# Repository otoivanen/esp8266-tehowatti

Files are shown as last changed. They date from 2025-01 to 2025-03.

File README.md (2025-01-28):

# Introduction
This project aims to create a custom device with esp8266 based microcontroller to track floor heating system's inlet- and outlet temperatures and allow to control the heating system's temperature dropping functionality.
The device can be integrated to any homeautomation system with MQTT capabilities.

- Reads two DS18B20 sensors
- Reports sensor values to selected MQTT topics
- Controls external components via relay, controllable with MQTT
- Display to show errors and status values
- LED to indicate statuses with guick glance
- Web UI for configuring the device, WiFi AP / WLAN
- Intended to integrate into Home Assistant

# Project structure
Project is a normal Arduino/ESP8266 created in VSCode PlatformIO extension - so the project structure differs a bit from traditional program created with Arduino IDE.

1) Install VSCode
2) Install PlatformIO extension
3) Clone the repository
4) Access the project through PlatformIO extension
5) Upload the program to device with PlatformIO
6) Upload the static files in Data directory to device SPIFFS with PlatformIO

The Data -directory contains all static files to be saved in the SPIFFS.

# Hardware
This is just an example of the bill of materials for the project. With small changes you can adapt your own hardware. List of hardware used in this project:
- Wemos D1 Mini
- 0.96" OLED I2C generic display
- 2x DS18B20 temperature sensors
- Relay board with 3.3V coil voltage
- WS1812B LED
- 3D printed case
- Cable glands
- Dupont wires
- Preferably Home Assistant or similar homeautomation system

## Case
The case has been designed with SolidWorks and needed STL & 3MF files are published in MakerWorld community
[Wemos D1 Mini project enclosure](https://makerworld.com/en/models/946838#profileId-913814)

# TO-DO
- Controllability
    - Implement relay class
    - Implement relay control through mqtt
    - Implement relay control through web ui
- Status indication
    - Implement sensor values & WiFi status to OLED display
    - Implement logics for status LED controlling
- Configuration
    - Implement assigning scanned sensor adresses into inlet/outlet temps via web UI
- Documentation
    - Draw wiring schema for device & boiler

# Images
##
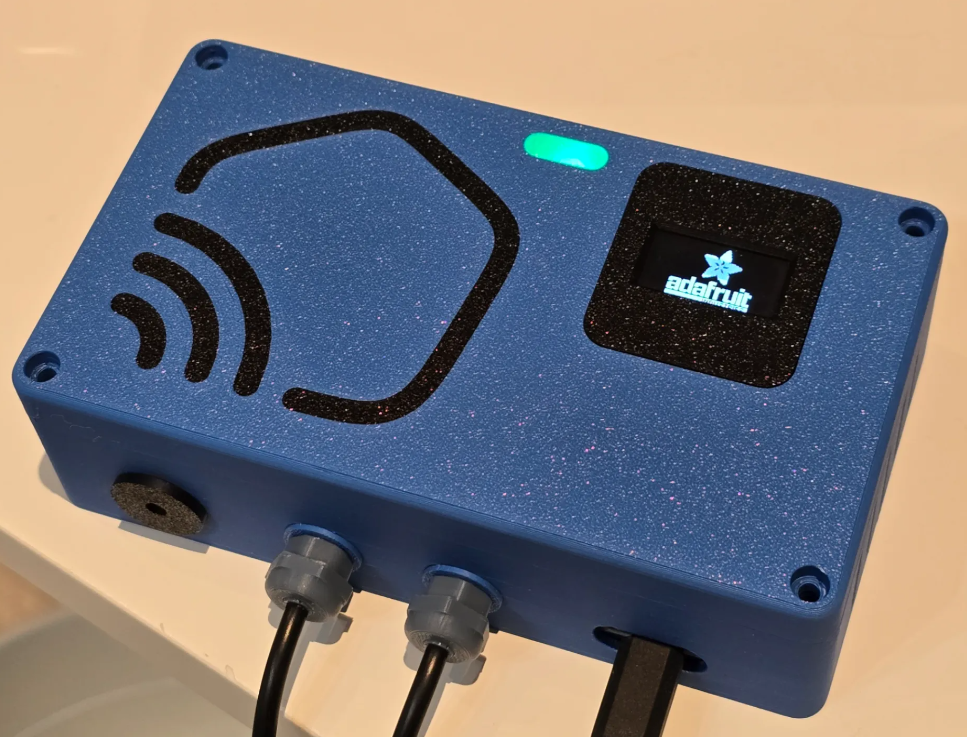
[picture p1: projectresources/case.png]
case


## Configuration UI runnin on AP or WLAN to store settings
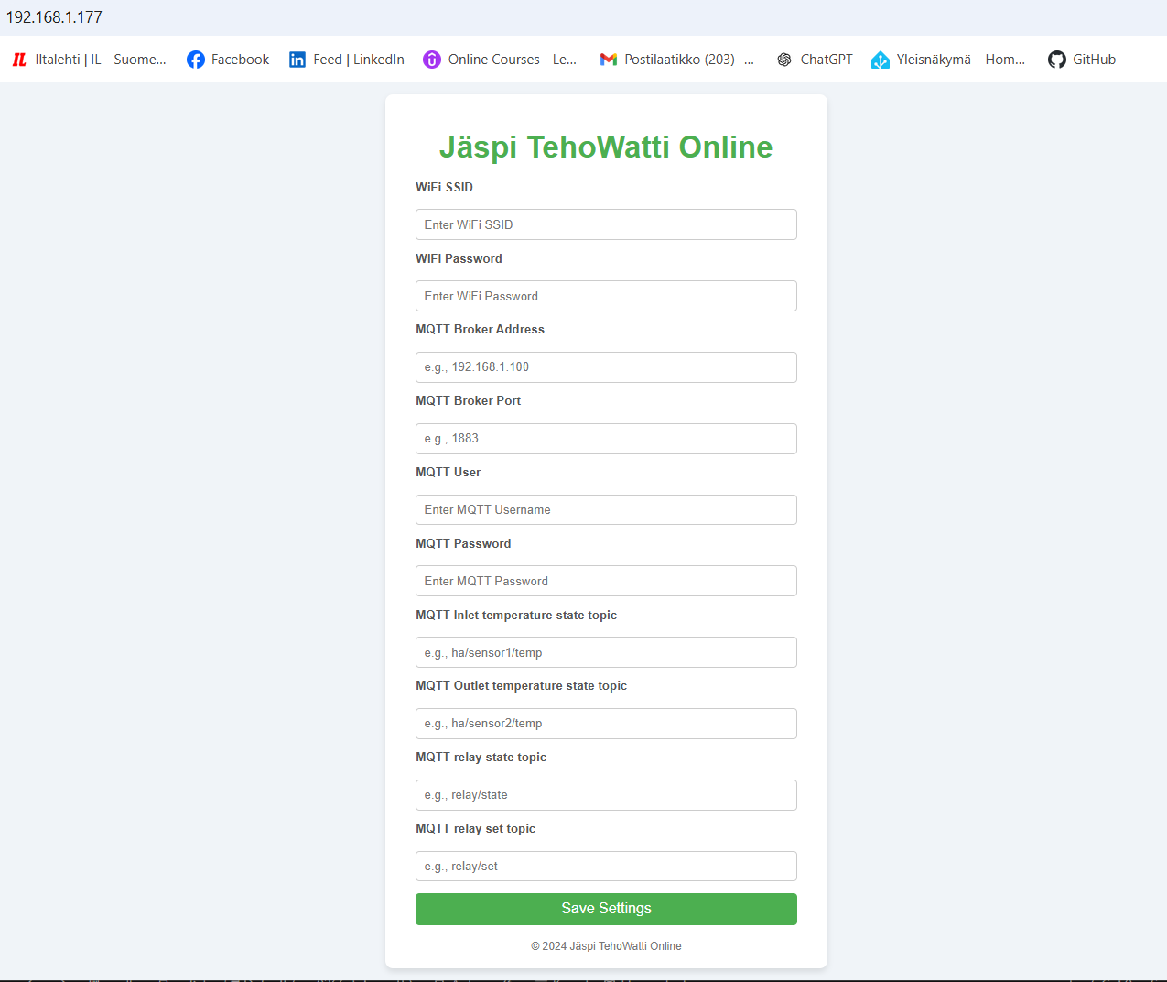
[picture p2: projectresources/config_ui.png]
configurationui


## Home assistant integration
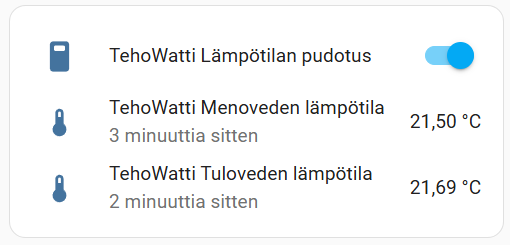
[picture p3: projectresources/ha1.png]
ha1

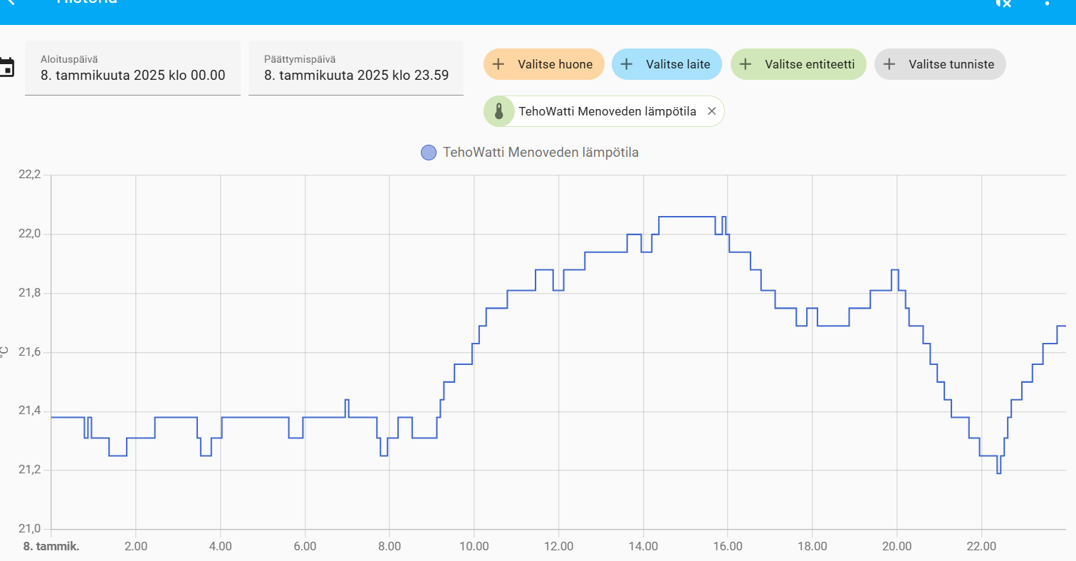
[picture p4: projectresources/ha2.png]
ha2


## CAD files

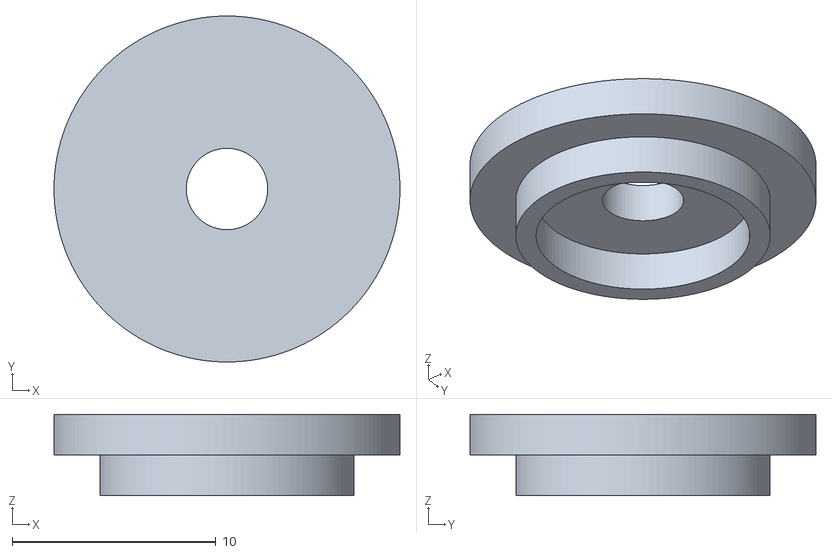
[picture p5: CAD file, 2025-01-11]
case/STL/CableGland1^case_assembly.STL
17.0 x 17.0 x 4.00

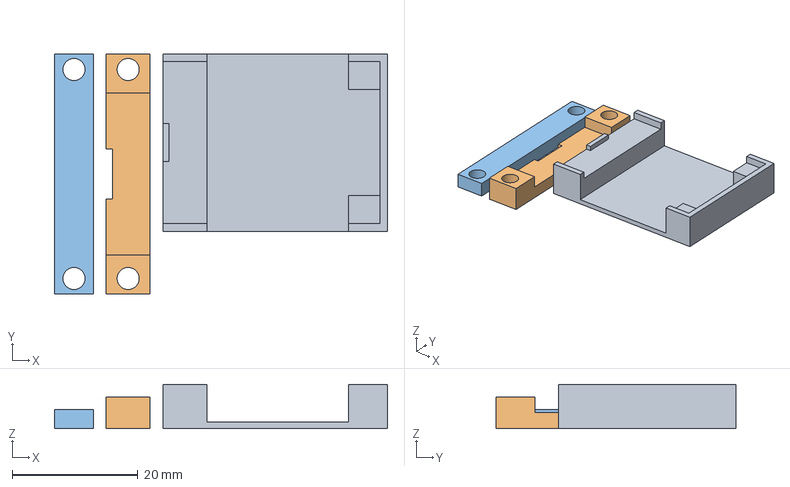
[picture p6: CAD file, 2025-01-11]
case/CradleAssembly.3mf
52.9 x 38.2 x 7.00 mm
CradleAssembly
CradleAssembly_3
CradleAssembly_2

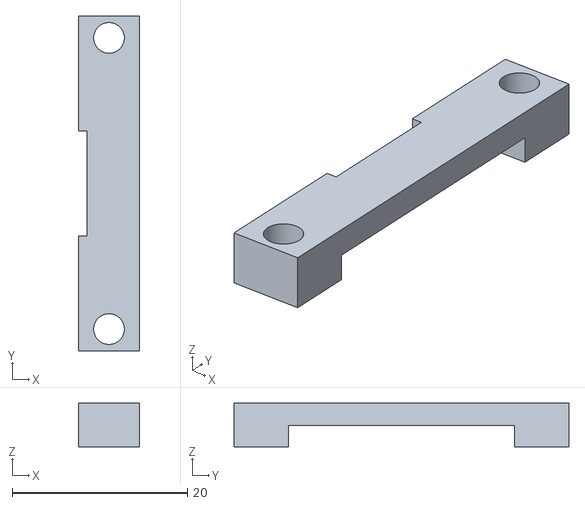
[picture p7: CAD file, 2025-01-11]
case/STL/Wemos_cradlelock_2^CradleAssembly.STL
7.00 x 38.2 x 5.00

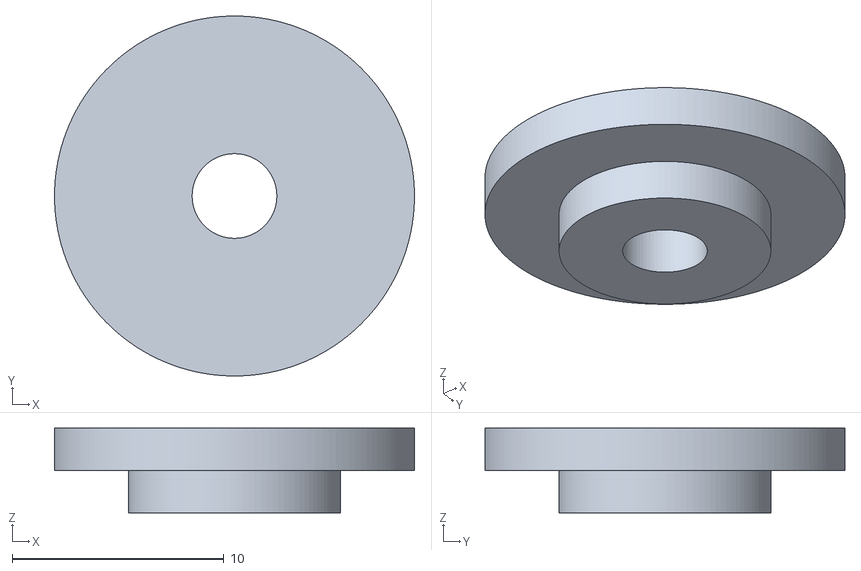
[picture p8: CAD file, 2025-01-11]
case/STL/CableGland2^case_assembly.STL
17.0 x 17.0 x 4.00

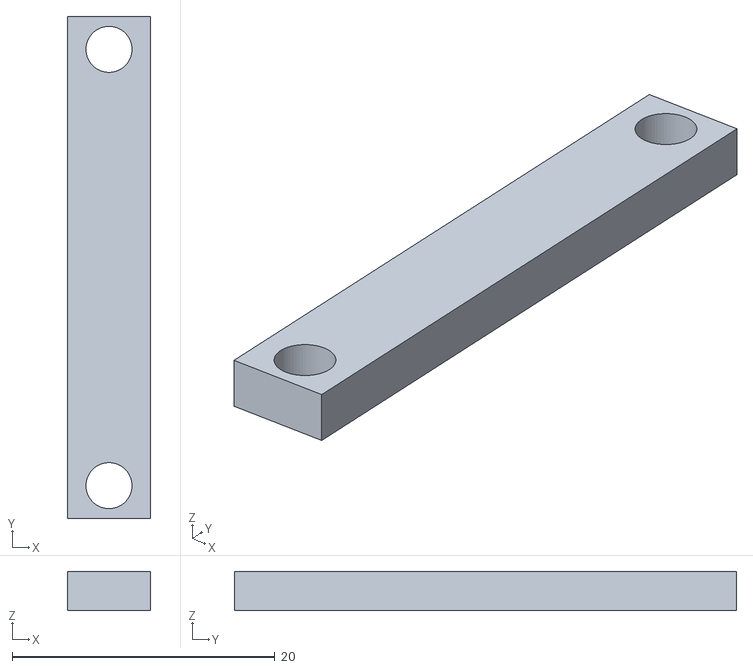
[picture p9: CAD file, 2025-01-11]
case/STL/Wemos_cradlelock_1^CradleAssembly.STL
6.30 x 38.2 x 3.00

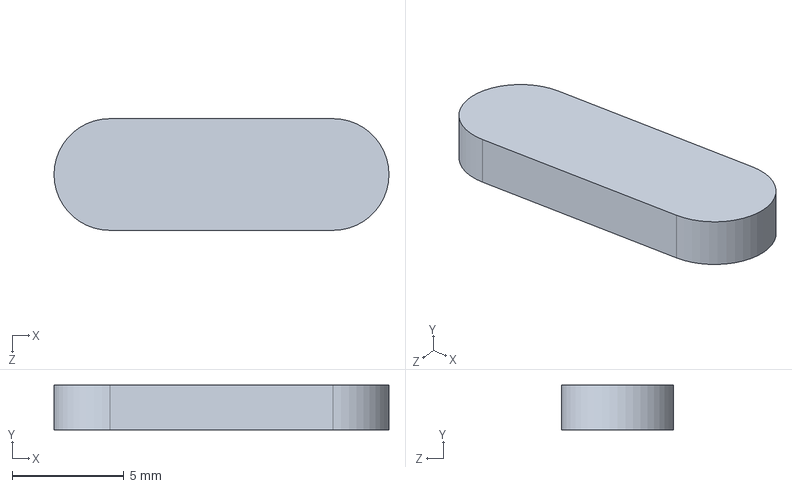
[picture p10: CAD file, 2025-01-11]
case/Body2.SLDPRT
15.0 x 2.00 x 5.00 mm

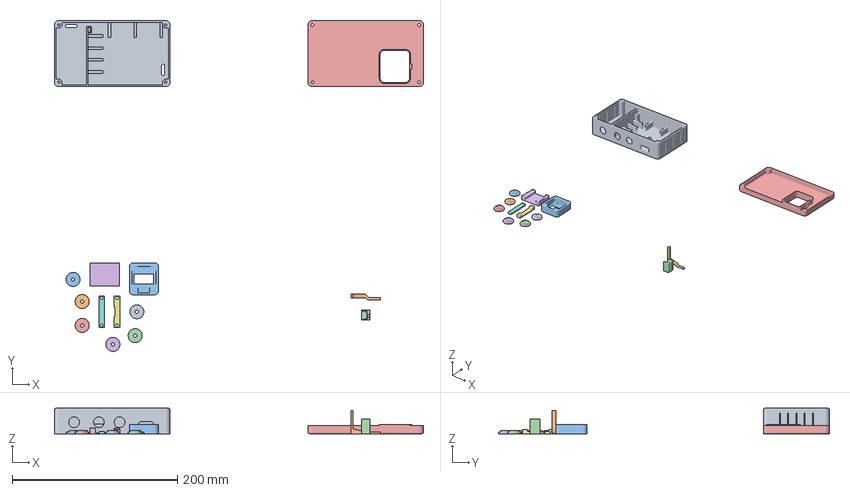
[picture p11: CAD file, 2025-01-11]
case/STL/case_project.3mf
447.2 x 400.9 x 31.0 mm
case_body.STL
Ledbase.STL
bezel.STL
LedCradle.STL
Assembly
Wemos_cradle.STL
Wemos_cradlelock_2^CradleAssembly.STL
Wemos_cradlelock_1^CradleAssembly.STL
CableGland2^case_assembly.STL x 3
CableGland1^case_assembly.STL x 3

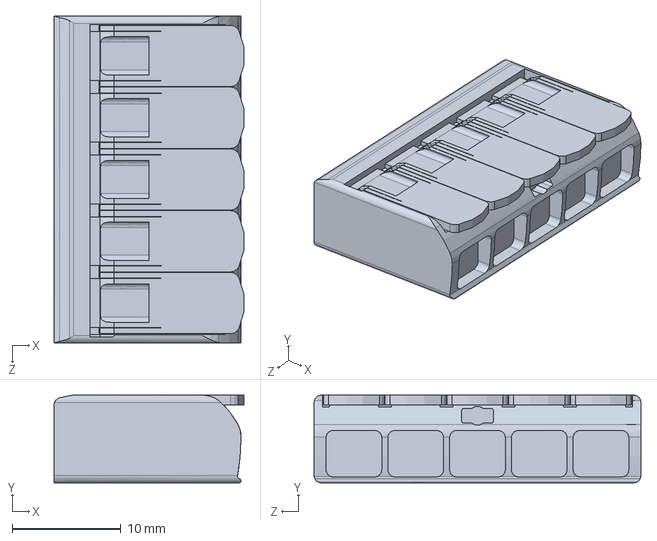
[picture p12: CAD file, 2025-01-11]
case/WAGO 221-615.SLDPRT
17.5 x 8.08 x 30.1 mm

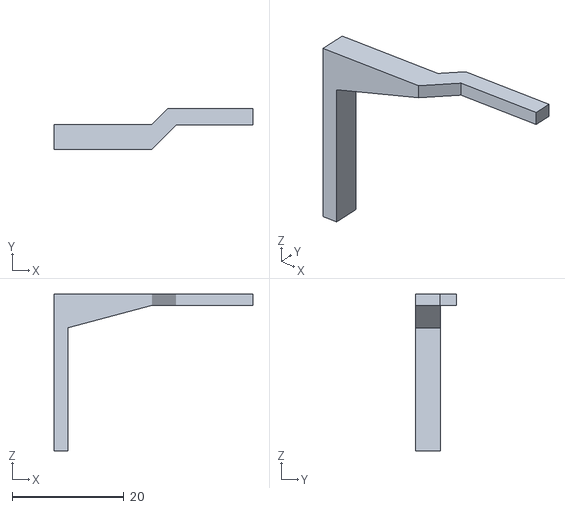
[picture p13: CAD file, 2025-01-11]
case/STL/Ledbase.STL
35.6 x 7.35 x 28.0

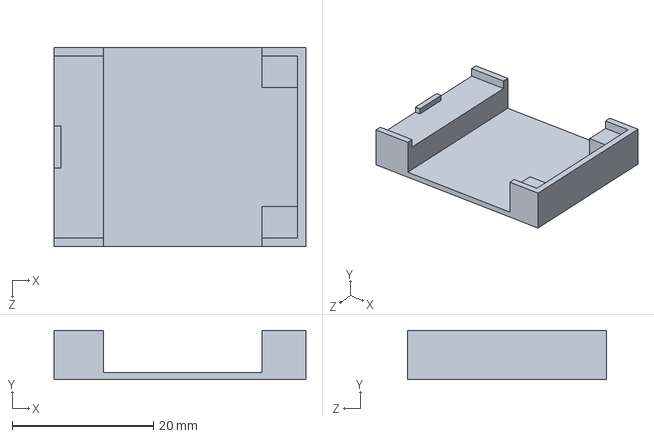
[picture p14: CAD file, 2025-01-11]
case/Wemos_cradle.SLDPRT
35.7 x 7.00 x 28.2 mm

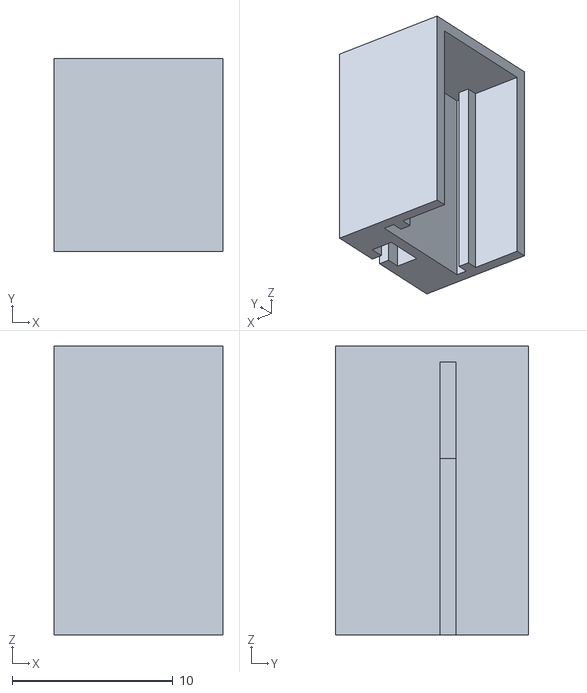
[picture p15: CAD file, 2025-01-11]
case/STL/LedCradle.STL
10.5 x 12.0 x 18.0

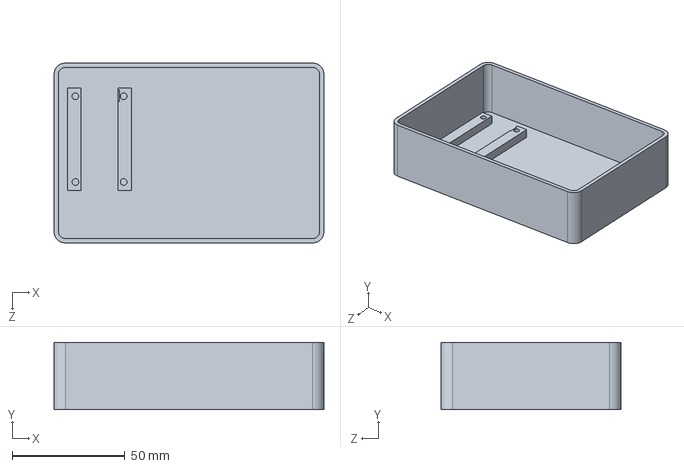
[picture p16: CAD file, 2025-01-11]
case/case_body.SLDPRT
120.0 x 30.0 x 80.0 mm

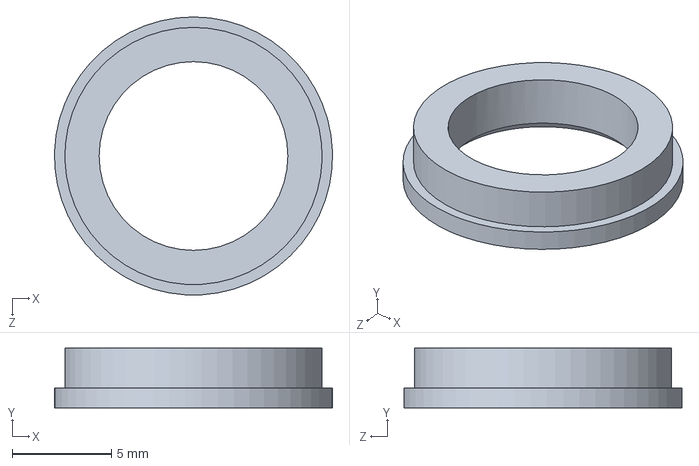
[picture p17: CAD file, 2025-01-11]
case/STL/cableGland_flange.SLDPRT
14.0 x 3.00 x 14.0 mm

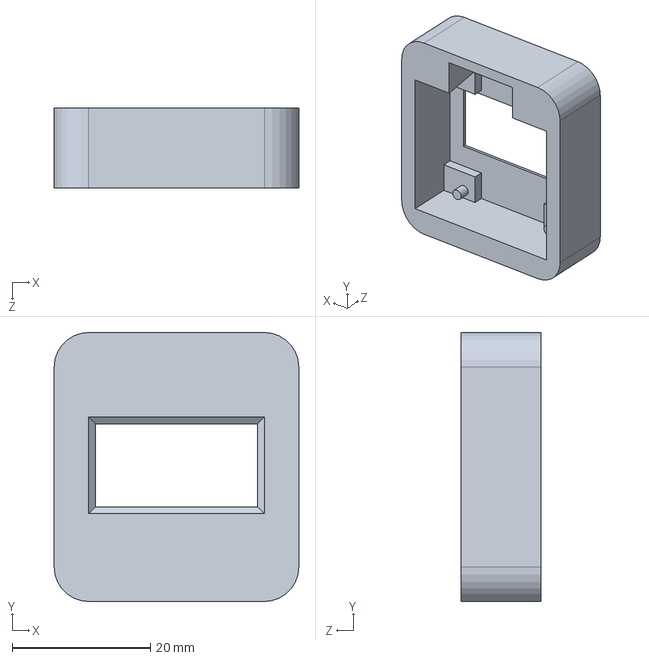
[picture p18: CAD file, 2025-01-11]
case/bezel.SLDPRT
35.4 x 38.9 x 11.5 mm

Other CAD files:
case/Relay.SLDPRT
case/STL/Lid.STL
case/Body4.SLDPRT
case/Body1.SLDPRT
case/Body3.SLDPRT
case/Cable gland.SLDPRT
case/M12 Thin hex nut.SLDPRT
case/STL/Wemos_cradle.STL
case/STL/bezel.STL
case/STL/cableGland_flange.STL
case/STL/case_body.STL
case/Wago serie 221.SLDPRT

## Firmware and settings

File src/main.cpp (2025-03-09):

/*
ESP8266-Tehowatti program controls a device that reads two DS18B20 temperature sensors, and reports the values through MQTT
to configurable topics. The program also controls a relay based on MQTT messages and/or HTTP-requests. The device can be configured and
status checked through WebUI served from the device's webserver.

Main program initializes the needed objects and performs the main loop of checking connections and connecting as needed, switching between STA/AP-modes,
handling MQTT-communication and HTTP-requests. The detailed logics of each functionality is encapsulated inside the corresponding class. Main events
of the main in addition to status checks and calling functions from other classes is to handle the MQTT-messaging. It includes also few global functions
to allow global messaging between multiple classes.

Author: Oskari Toivanen
Date: 2025-03-09
*/

#include <Arduino.h>
#include <WiFiManager.h>
#include <WebServerManager.h>
#include <secrets.h>
#include <FileManager.h>
#include <ArduinoJson.h>
#include <PubSubClient.h>
#include <SensorManager.h>
#include <ConfigManager.h>
#include <Wire.h>
#include <Adafruit_NeoPixel.h>
#include <Relay.h>
#include <Global_functions.h>
#include <OLEDManager.h>
#include <LEDManager.h>

const int ONE_WIRE_PIN = 16; // Pin where onewire sensors are connected
const char* DEVICE_NAME = "TehoWatti";
unsigned long MQTT_RECONNECT_INTERVAL = 10000;
unsigned long SENSOR_VALUE_MIN_PUBLISH_INTERVAL = 5000;
unsigned long SENSOR_VALUE_MAX_PUBLISH_INTERVAL = 300000; // Publish sensor values every 5 mins minimum
unsigned long RELAY_STATE_PUBLISH_INTERVAL = 300000; // Publish relay state by force every 5 mins

FileManager fm; // Filemanager object for reading & writing to files
WiFiManager wm; // WiFiManager object to control WiFi connectivity
WiFiClient wiFiClient; // Initialize separate WiFi Client to interact with mqtt server on different port
PubSubClient mqttClient(wiFiClient); // Mqtt client for mqtt messaging
SensorManager sensors(ONE_WIRE_PIN); // Initialize the sensor manager
ConfigManager config(fm);
Relay relay(14); // Initialize relay in output pin 14
WebServerManager server(80, config, sensors, relay); // Webserver to run on port 80 for http connections
OLEDManager oled; // Init display object
LEDManager led; // Init the led control


// Declare function prototypes here to place them below loop () for better readability
void connectMqtt();
bool isPublishAllowed();
void publishSensorValues();
void callback(char* topic, byte* payload, unsigned int length);
void publishRelayState();

void setup() {
  // Initialize and start the display
  oled.begin(SSD1306_SWITCHCAPVCC, 0x3C);
  oled.showBootMsg("Booting..");

  // Initialize and start the led operation, show alert color until fully booted
  led.enable();
  led.alert();

  Serial.begin(9600); // Open the serial port
  fm.begin(); // Initialize the FS
  config.loadConfig(); // Load all configs from file

  // Set the sensor addresses from config
  sensors.setInletSensorAddress(config.getInletSensorAddress());
  sensors.setOutletSensorAddress(config.getOutletSensorAddress());

  wm.setCredentials(config.getSSID(), config.getWiFiPassword(), DEVICE_NAME);
  
  oled.showBootMsg("Trying to establish WiFi Connection");
  if(!wm.connect()) {
    oled.showBootMsg("WiFi failed, starting AP");
    wm.startSoftAP();
  }

  server.begin(); // Start the web server
  mqttClient.setServer(config.getMqttServer(), config.getMqttPort());
  mqttClient.setKeepAlive(15);
  mqttClient.setCallback(callback); // Assign callback function to execute when MQTT-msg is received
  connectMqtt();
  
  oled.clearDisplay();
  oled.display();
}

void loop() {
  // Update the status led state on every cycle
  led.setStatus(wm.isAPOn(), mqttClient.connected(), relay.getState());

  // Ensure wifi is connected, if not start softAP for a period of time before reconnecting
  wm.checkWiFiStatus(); 

  // Ensure mqtt broker is connected and attempt reconnect if not
  if (!mqttClient.connected() && !wm.isAPOn()) {
    connectMqtt();
  }

  server.handleClient();    // Handle the webserver client requests
  wm.checkAPClientCount();  // Check nbr of softap clients if established. Non-blocking function.
  sensors.readSensors();    // Read the sensor values on interval specified in the sensor class
  mqttClient.loop();        // Handle MQTT-messages
  publishSensorValues();    // Publish sensor values
  publishRelayState();      // Force publish relay state in case of unknown state

  // Update the OLED -display rows if states have changed
  oled.updateDisplay(sensors.getInletTemp(), sensors.getOutletTemp(), relay.getState(), wm.getIP(), wm.getMode(), mqttClient.connected());
}

/**
 * @brief Checks MQTT-connection status and reconnects on preset interval if needed
 * 
 * If WiFi-connection is established, and time defined in MQTT_RECONNECT_INTERVAL constant
 * has passed, device retries the connection to MQTT-broker. After succesful connection the needed
 * topics are being subscribed.
 */
void connectMqtt() {
  static unsigned long lastConnectionAttempt = 0;

  if(wm.status() == WL_CONNECTED && millis() - lastConnectionAttempt > MQTT_RECONNECT_INTERVAL) {

    Serial.println("Trying to establish mqtt broker connection");

    if(mqttClient.connect(DEVICE_NAME, config.getMqttUser(), config.getMqttPassword())) {
      Serial.println("Connected to mqtt broker succesfully");
      mqttClient.subscribe(config.getRelaySetTopic()); // Subscribe to relay set topic for receiving control msg
    } else {
      Serial.print("Failed to connect mqtt broker with errorcode: ");
      Serial.println(mqttClient.state());
    }

    lastConnectionAttempt = millis();
  }
}

/**
 * @brief Determines if a sensor value is allowed to be published over MQTT
 * 
 * The function checks two conditions to allow publishing:
 * 1. If the elapsed time since last publish exceeds the minimum interval and
 * the temperature change exceeds a defined treshold (0.1c)
 * 2. If the maximum allowed publish interval has been exceeded, regardless of temperature change
 * 
 * Additionally, publishing is allowed only if the MQTT client is currently connected.A0
 * 
 * @param lastPublish the timestamp (in milliseconds) of the last succesful publish
 * @param lastTemp the last published temperature value
 * @param currentTemp the current temperature reading
 * @return true if publishing is allowed based on the condition, false otherwise
 */
bool isPublishAllowed(unsigned long &lastPublish, float &lastTemp, float &currentTemp) {
  unsigned long fromLastPublish = millis() - lastPublish;

  if (!mqttClient.connected()) { return false; }

  if((fromLastPublish > SENSOR_VALUE_MIN_PUBLISH_INTERVAL && abs(lastTemp - currentTemp) > 0.1) || fromLastPublish > SENSOR_VALUE_MAX_PUBLISH_INTERVAL) {
    return true;
  }
  
  return false;
}

/**
 * @brief Handles the publishing of the sensor values to MQTT broker.
 * 
 * The function maintains the previous temperature- and publishtime values for determining if publishing is allowed.
 * Function fetches latest readings for both sensors and publishes the values into MQTT topics defined in configs if allowed.
 */
void publishSensorValues() {
  static unsigned long lastInletTempPublish = 0; // static will retain the value from last execution
  static unsigned long lastOutletTempPublish = 0;

  char buffer[16]; // Shared buffer for publishing

  float inletTemp = sensors.getInletTemp();
  static float lastInletTemp = 0;
  float outletTemp = sensors.getOutletTemp();
  static float lastOutletTemp = 0;

  // Publish inletTemp
  if(isPublishAllowed(lastInletTempPublish, lastInletTemp, inletTemp)) {
    dtostrf(inletTemp, 6, 2, buffer); // Convert float to string
    mqttClient.publish(config.getInletTempStateTopic(), buffer);
    Serial.print("Inlet temperature published: ");
    Serial.println(inletTemp);
    lastInletTempPublish = millis();
    lastInletTemp = inletTemp;
  }

  // Publish outletTemp
  if(isPublishAllowed(lastOutletTempPublish, lastOutletTemp, outletTemp)) {
    dtostrf(outletTemp, 6, 2, buffer); // Convert float to string
    mqttClient.publish(config.getOutletTempStateTopic(), buffer);
    Serial.print("Outlet temperature published: ");
    Serial.println(outletTemp);
    lastOutletTempPublish = millis();
    lastOutletTemp = outletTemp;
  }
}

/**
 * @brief Callback function executed whenever an MQTT message is received from the broker.
 * 
 * This function is triggered automatically when a subscribed MQTT topic receives a message. 
 * It parses the incoming payload, converts it to a string, and processes the message.
 * If the message is "ON" or "OFF", it updates the relay state accordingly.
 * 
 * @param topic The MQTT topic on which the message was received.
 * @param payload The actual message data in byte format.
 * @param length The length of the incoming message payload.
 */
void callback(char* topic, byte* payload, unsigned int length) {

  char message[10]; // Buffer large enough for "ON", "OFF", and null terminator

  memcpy(message, payload, length); // Copy payload into buffer
  message[length] = '\0'; // Null-terminate the string

  Serial.println("Message received on topic: ");
  Serial.println(topic);
  Serial.println("Message: ");
  Serial.println(message);

  if (strcmp(message, "ON") == 0) {
    setRelayState(true);
  } else if (strcmp(message, "OFF") == 0) {
    setRelayState(false);
  }
}

/**
 * @brief Publishes the relaystate (on/off) with defined interval to make sure MQTT broker is synced with device status
 * 
 * The function checks if MQTT connection is established, and the defined time interval has passed between last publish.
 */
void publishRelayState() {
  static unsigned long lastRelayStatePublish = 0;

  if(mqttClient.connected() && (millis() - lastRelayStatePublish > RELAY_STATE_PUBLISH_INTERVAL || lastRelayStatePublish == 0)) {
    mqttClient.publish(config.getRelayStateTopic(), relay.getState());
    lastRelayStatePublish = millis();
    Serial.println("Relay state published");
  }
}

/**
 * @brief Global function to set relay state and perform sequence of actions related to relay statechange
 * 
 * Based on the command function sets relay activated or deactivated, and sends the state message to MQTT broker
 * which keeps other devices aware of the state. Function also switches the LED-indicator to show blue / standby
 * based on state changes. Being a global function it can be accessed from any class and thus the relay, LED and
 * MQTT message are sent regardless if state change was requested through HTTP-request or MQTT message.
 * 
 * @param state true switches the relay active, false deactivates the relay
 */
void setRelayState(bool state) {
  if (state) {
    relay.on();
    mqttClient.publish(config.getRelayStateTopic(), "ON", true);
    led.relayActive();
  } else {
    relay.off();
    mqttClient.publish(config.getRelayStateTopic(), "OFF", true);
    led.standby();
  } 
}

/**
 * @brief Function returns the JSON-string containing all necessary states of the device for displaying in UI
 * 
 * Function checks the WiFi state (AP/STA) and gets the SSID from wifi controller. Then JSON
 * object is then formed by getting the states and configs from all necessary classes. Function is defined as
 * global to be accessible from WebServer class, and still being able to gather states from all objects
 * 
 * @return JSON-string containing necessary configs and states for WebUI
 */
String getStatesAsJson() {
  JsonDocument doc;

  String currentSSID;

  if (wm.getMode() == "STA") {
    currentSSID = wm.SSID();
  } else {
    currentSSID = wm.softAPSSID();
  }

  // Populate JSON document with current config values
  doc["wifiMode"] = wm.getMode();
  doc["wifiIP"] = wm.getIP();
  doc["SSID"] = currentSSID;
  doc["MQTTConnected"] = mqttClient.connected();
  doc["MQTTBroker"] = config.getMqttServer().toString();
  doc["MQTTPort"] = config.getMqttPort();
  doc["InletTemp"] = sensors.getInletTemp();
  doc["OutletTemp"] = sensors.getOutletTemp();
  doc["RelayState"] = relay.getState();
  doc["inletSensorAddress"] = sensors.getInletSensorAddress();
  doc["outletSensorAddress"] = sensors.getOutletSensorAddress();

  // Serialize JSON document into a string
  String serializedStates;
  serializeJson(doc, serializedStates);

  return serializedStates;
}

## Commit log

2024-12-20 Add mqtt functions. Consider making struct or class from sensor data
2024-12-21 Introduce SensorManager and ConfigManager classes to handle sensors and config management. Refactor code.
2024-12-27 Publishing temps to ha topics configurable via ui. Also wifi breakdowns are handled by switching to AP for intervals and attempting to reconnect.
2025-01-11 Include case sldprt and stl files to repo, change sensor pin
    [Body1.SLDPRT, Body2.SLDPRT, Body3.SLDPRT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]
2025-01-11 Add display & led test snippets
2025-02-25 Add relay class and mqtt & http controls
2025-02-26 ad LED class with state tracking
2025-03-09 add sensor config and sensor reading by address
